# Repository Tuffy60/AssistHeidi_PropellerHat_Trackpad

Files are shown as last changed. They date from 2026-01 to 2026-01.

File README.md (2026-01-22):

# ASSIST HEIDI – Assistive Input System

ASSIST HEIDI is an assistive input system developed to provide alternative and accessible input devices for users who experience difficulties using standard mouse and keyboard setups.  
The project focuses on reducing physical strain while maintaining precise and responsive control, especially for fast-paced applications such as shooter games.

This repository contains the complete firmware, hardware design files, and documentation created as part of the ASSIST HEIDI project.

---

## Project Background

The project was developed in close collaboration with a user who experiences rapid fatigue and reduced precision when using conventional input devices.  
Standard gaming peripherals often require continuous hand positioning, repetitive movements, and frequent button presses, which can significantly limit comfort and usability over longer sessions.

ASSIST HEIDI aims to address these challenges by offering customizable and modular input solutions that adapt to individual needs rather than forcing the user to adapt to the device.

---

## Features

- Assistive **trackpad-based controller** for precise cursor movement
- **Two easily accessible buttons** for mouse or keyboard actions
- **Seven-switch mini keyboard controller** with fully customizable mappings
- Adjustable firmware parameters:
  - cursor speed
  - sensitivity
  - rotation (0°, 90°, 180°, 270°)
- Standard **USB Human Interface Device (HID)** behavior
- Plug & Play – no additional drivers required
- Platform independent (Windows, macOS, Linux)

---

## Repository Structure

- [firmware/trackpad_input](firmware/trackpad_input/) – Assistive trackpad and button input module
- [firmware/Keyboard_Switch](firmware/Keyboard_Switch/) – Assistive Keyboard for game controls  
- [hardware/3D_prints](hardware/3D_print/) – 3D printable parts

---
## Firmware

The firmware is implemented using the **Arduino framework** and runs on the **Raspberry Pi Pico W**.  
All configuration parameters are defined directly in the source code:

- `.h` files contain configurable mappings and feature definitions  
- `.cpp` files control behavior such as sensitivity, speed, and smoothing  

The device is recognized by the host system as a standard mouse and keyboard using USB HID.

---

## Hardware

The controllers are built using off-the-shelf components and 3D-printed enclosures.  
No specialized manufacturing tools are required, making the system easy to reproduce and modify.

3D printing files are provided in the [hardware/3D_prints](hardware/3D_print/) directory.

---

## Documentation

A detailed project documentation including:
- problem description
- solution overview
- materials and costs
- technical details
- assembly instructions

is available as a PDF in this repository:

📄 [PropellerHat-Controller_Documentation.pdf](PropellerHat-Controller_Documentation.pdf)

---

## License

This project is released under the **MIT License**.  
You are free to use, modify, and distribute the code and design files.

---

## Contributors

- Ates Tufan  
- Jakob Brandstetter  
- Matteo Fachino

---

## Acknowledgements

This project was developed as part of the **ASSIST HEIDI** initiative and builds upon previous assistive controller concepts.  
Special thanks to the user involved in the co-creation process for valuable feedback and continuous testing.

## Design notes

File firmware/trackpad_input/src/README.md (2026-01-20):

# Assistive Trackpad & Button Input Module (Arduino / USB HID)

This repository contains the implementation of an **assistive input system**
developed as part of the **ASSIST HEIDI** project.
The system is designed for people with **motor impairments affecting hands,
arms or overall body coordination** and provides an alternative way to
interact with a computer using minimal and controlled movements.

The device behaves as a standard USB mouse and keyboard and does not require
any special drivers on the host system.

---

## Overview

The system consists of the following components:

- A Cirque capacitive trackpad used as a pointing device  
- Two hardware buttons configurable as mouse or keyboard inputs  
- A USB HID interface exposing mouse and keyboard functionality  

The implementation focuses on:

- Accessible and low-fatigue interaction  
- Stable and predictable cursor movement  
- Suppression of involuntary micro movements  
- Deterministic behavior without automatic guessing  
- Clear separation of software modules  

---

## Features

- USB HID mouse and keyboard support  
- Configurable hardware buttons  
- Trackpad movement with deadzone, acceleration and smoothing  
- Controlled edge scrolling  
- Explicit rotation modes (0°, 90°, 180°, 270°)  
- Non-blocking input handling  
- Fully documented and modular code structure  

---

## Project Structure
.
├── main.cpp # Application entry point
├── trackpad.h # Trackpad interface and data structures
├── trackpad.cpp # Trackpad processing logic
├── buttons.h # Button configuration and action definitions
├── buttons.cpp # Button handling and HID actions
├── cirque.h # Cirque trackpad driver (external)
├── cirque.cpp # Cirque trackpad driver (external)
└── README.md

---

## Hardware Requirements

- Arduino-compatible microcontroller with native USB support  
  (e.g. RP2040, ATmega32U4, etc.)
- Cirque capacitive trackpad
- Two momentary push buttons
- USB connection to host PC

---

## Software Requirements

- Arduino framework
- USB HID support (`Mouse.h`, `Keyboard.h`)
- Compatible board package for the target microcontroller

---

### Supported Mouse Actions

The hardware buttons can be mapped to:

- Left mouse click  
- Right mouse click  
- Middle mouse click  
- Back and forward navigation buttons  

These actions enable basic system interaction without requiring precise or
fast finger movements.

### Supported Keyboard Actions

Buttons can also be mapped to keyboard inputs, including:

- Alphanumeric keys (e.g. W, A, S, D)  
- Arrow keys (Up, Down, Left, Right)  
- Modifier keys (Shift, Ctrl, Alt)  
- Common control keys (Space, Enter, Escape, Tab)  
- Function keys (F1 – F12)  

Each button generates a **press event when activated** and a **release event
when released**, ensuring stable and predictable USB HID behavior.

---

## Configuration Overview

### Button Configuration

Button behavior is configured in `buttons.h` using preprocessor definitions:

cpp
#define BUTTON1_ACTION   ACT_MOUSE_LEFT
#define BUTTON2_ACTION   ACT_MOUSE_RIGHT

Changing these values assigns a different mouse or keyboard action to the
corresponding hardware button.

This allows caregivers or developers to adapt the device to individual user
needs without modifying the button logic itself.

## Trackpad Movement and Accessibility Tuning

The trackpad behavior can be adjusted via `#define` parameters in
`trackpad.cpp` to match individual motor abilities.

Key parameters include:

- `SENS` – overall cursor movement speed  
- `SMOOTHING` – balance between responsiveness and stability  
- `DEADZONE_CENTER` – suppression of involuntary micro movements  
- `EDGE_SPEED_BASE` / `EDGE_SPEED_MAX` – controlled edge scrolling  

All parameters are documented directly in the source code.

---

## Assistive Design Principles

- Focus on stability rather than raw speed  
- Deterministic input behavior without automatic guessing  
- Minimal required movement for common actions  
- Adaptable configuration for different physical limitations  
- Designed for long-term and everyday use  

This module represents the technical implementation of the assistive input
concept developed within the **ASSIST HEIDI** project.

---

## Usage

1. Flash the firmware to the target microcontroller  
2. Connect the device to a PC via USB  
3. The device appears as a standard mouse and keyboard  
4. Use the trackpad for cursor movement  
5. Use the hardware buttons for mouse or keyboard actions  

No additional drivers are required.

---

This module was implemented and documented as part of an academic project.

Propeller-Controller

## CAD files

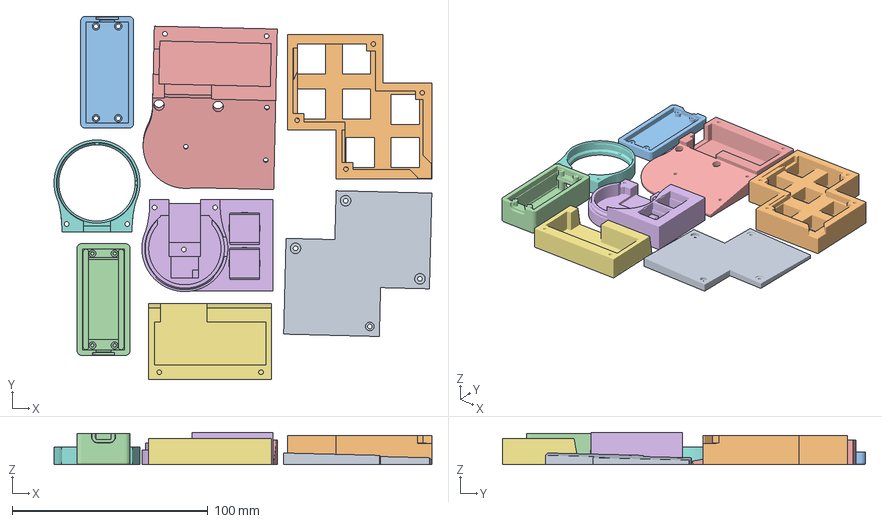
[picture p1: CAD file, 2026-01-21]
hardware/3D_print/Total_Project_Printing.3mf
193.4 x 185.8 x 16.5 mm
Base_slope5_7Switches_.stl
Main_7Switches_.stl
Botttom_case.stl
Top_case.stl
Base_TouchPad.stl
Main_TouchPad.stl
MicroController_Lid_TouchPad.stl
Top_TouchPad.stl

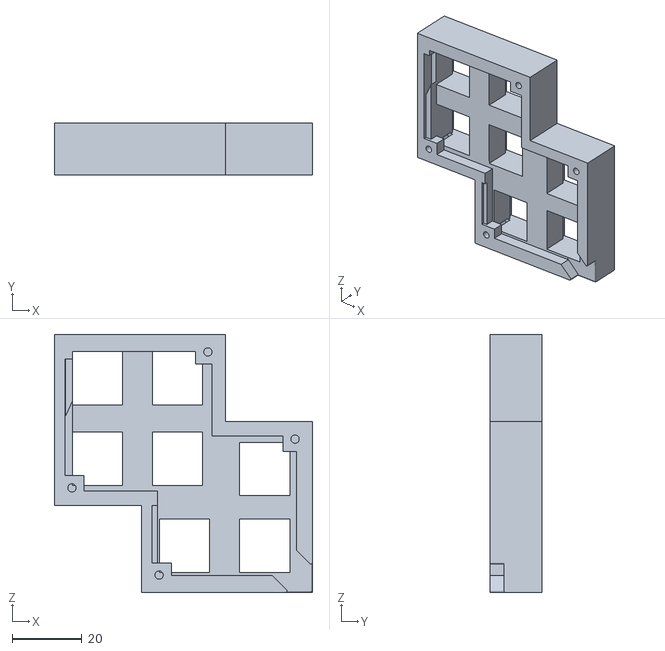
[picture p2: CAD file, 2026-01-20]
hardware/3D_print/7Switches/Main_7Switches_.stl
74.0 x 15.0 x 74.0

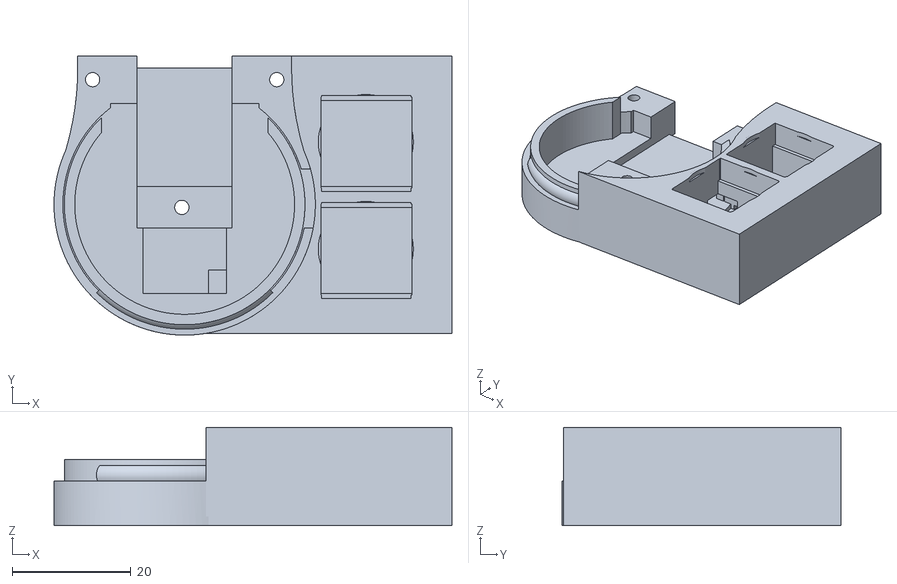
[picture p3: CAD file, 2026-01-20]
hardware/3D_print/TouchPad/Main_TouchPad.stl
67.0 x 47.0 x 16.5

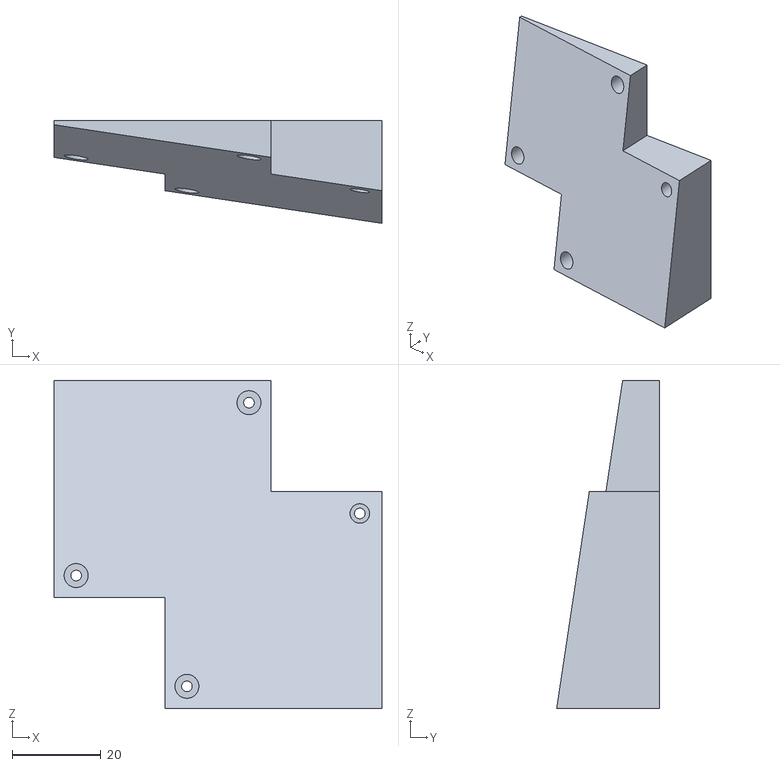
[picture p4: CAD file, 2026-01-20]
hardware/3D_print/7Switches/Base_slope23_7Switches_.stl
74.0 x 23.2 x 74.0

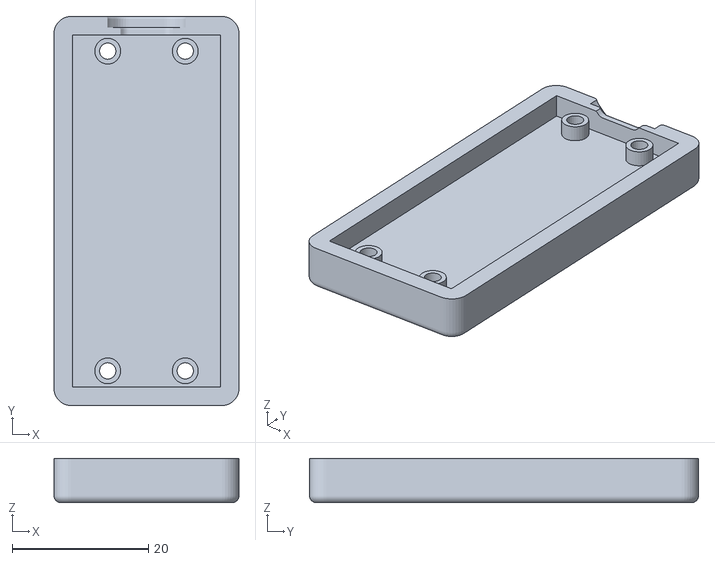
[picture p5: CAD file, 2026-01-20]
hardware/3D_print/Microcontroller_Case/Botttom_case.stl
27.2 x 57.2 x 6.50

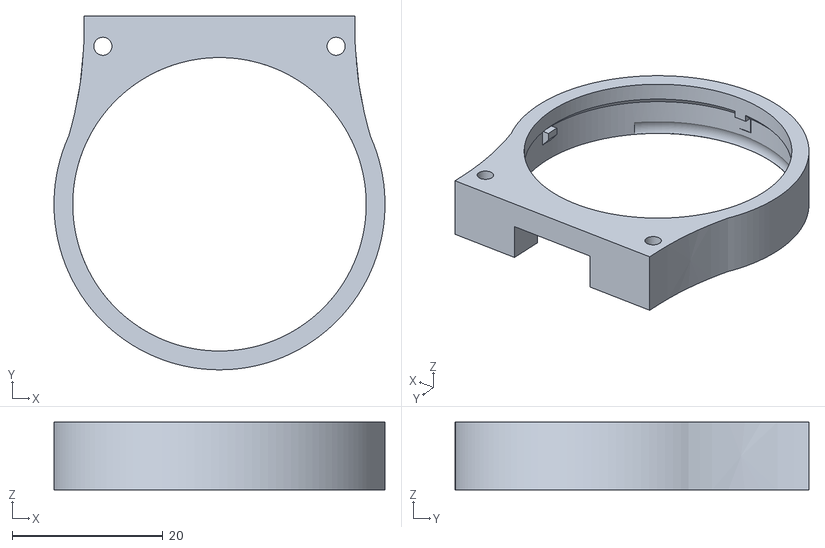
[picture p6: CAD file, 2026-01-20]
hardware/3D_print/TouchPad/Top_TouchPad.stl
44.0 x 47.0 x 9.00

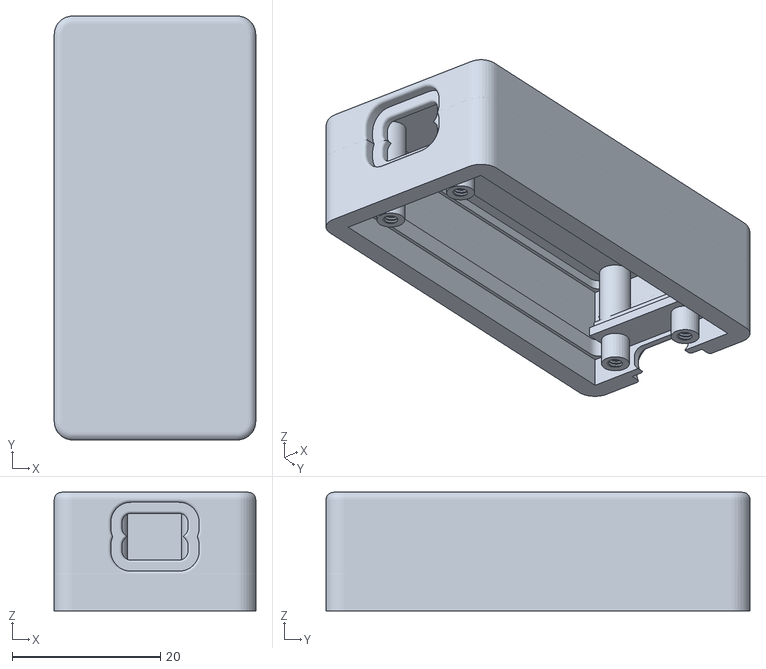
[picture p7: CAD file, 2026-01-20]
hardware/3D_print/Microcontroller_Case/Top_case.stl
27.2 x 57.2 x 16.0

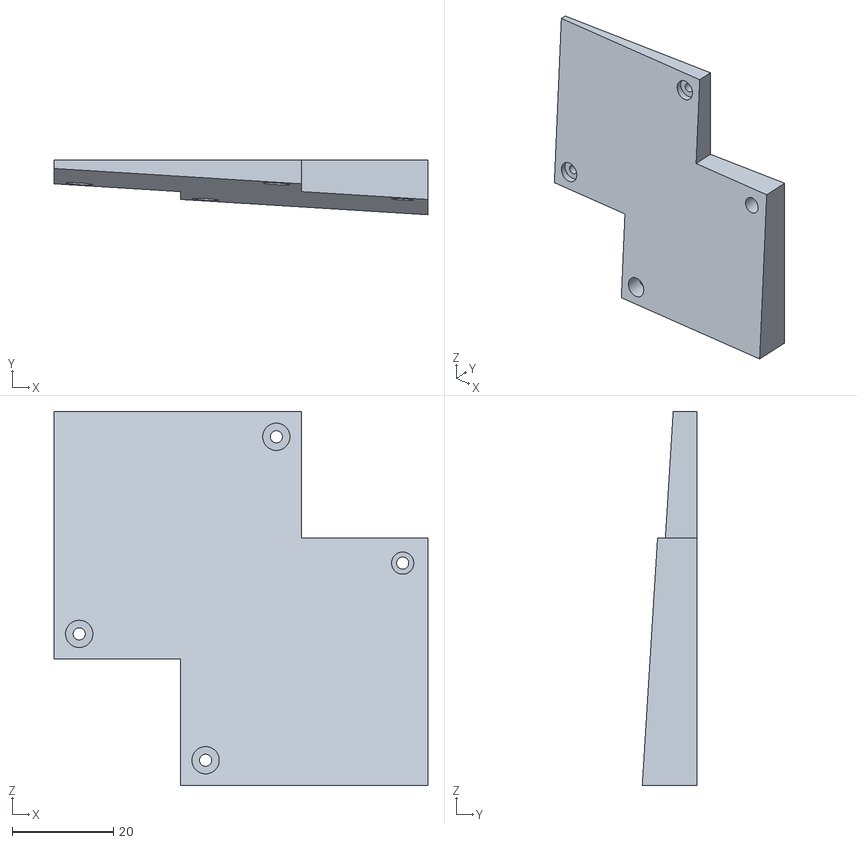
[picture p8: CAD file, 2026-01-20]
hardware/3D_print/7Switches/Base_slope10_7Switches_.stl
74.0 x 10.8 x 74.0

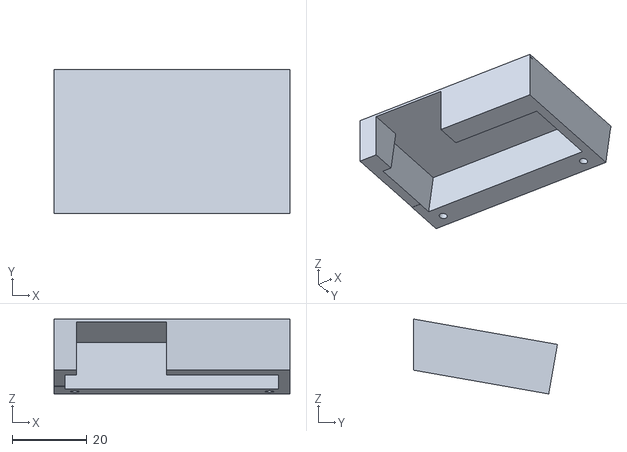
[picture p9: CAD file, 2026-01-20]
hardware/3D_print/TouchPad/MicroController_Lid_TouchPad.stl
63.0 x 38.4 x 20.0

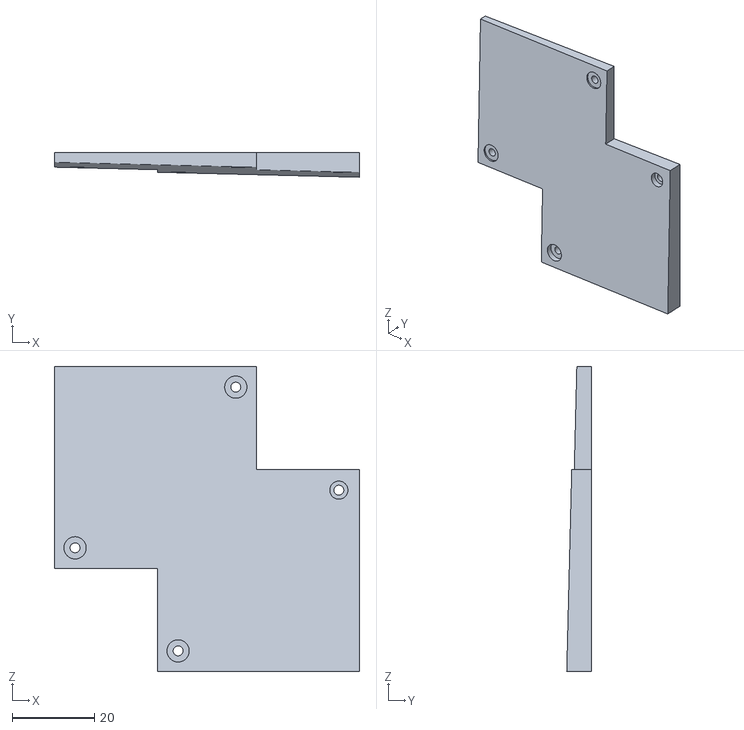
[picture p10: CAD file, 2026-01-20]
hardware/3D_print/7Switches/Base_slope5_7Switches_.stl
74.0 x 5.95 x 74.0

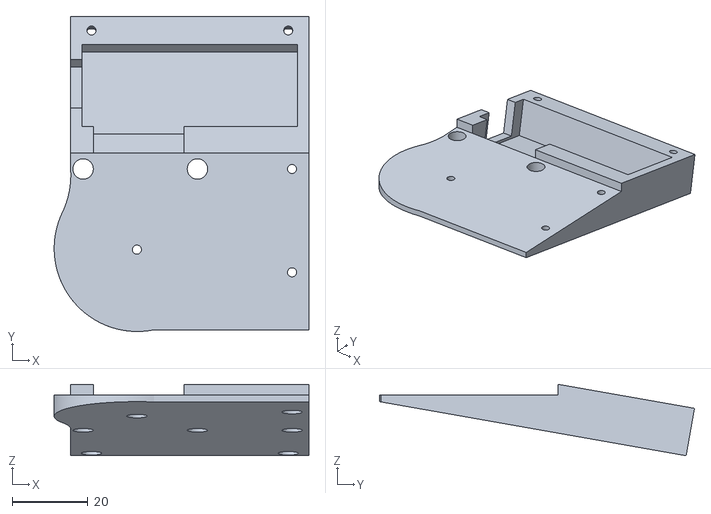
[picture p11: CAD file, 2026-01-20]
hardware/3D_print/TouchPad/Base_TouchPad.stl
67.3 x 83.2 x 18.9

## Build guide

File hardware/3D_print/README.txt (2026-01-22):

In this directory you find the 3 elemente of our design:
1) TouchPad Controller
2) 7 Switches - kebors controller
3) Secondary microcontroller case

and also the printing project with all components 'Total_Project_Printing.3mf'

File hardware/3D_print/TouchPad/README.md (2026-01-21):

In this folder you can find the design of Touchpad Controller, 
that consists of four distinct printed components:
1)	Inclined Base and Lower Housing (Base_TouchPad.stl)
This part provides the ergonomic tilt and forms the lower shell of the enclosure.
2)	Microcontroller Compartment Lid (MicroController_Lid_TouchPad.stl)
 A removable cover that protects the microcontroller and allows access for wiring and   maintenance.
3)	Main Body with Touchpad Mount and Switch Compartments (Main_TouchPad.stl)  
This central block integrates the mounting surface for the touchpad and the housing for the two auxiliary switches.
4)	Touchpad Outer Frame  (Top_TouchPad.stl)
A protective enclosure that secures the touchpad in place while leaving the active surface fully accessible.

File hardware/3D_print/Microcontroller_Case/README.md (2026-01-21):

In this folder you can find the design of Secondary Microcontroller Case:
1)	Base Plate (Bottom_case.stl)
2)	Top Cover (Top_case.stl)

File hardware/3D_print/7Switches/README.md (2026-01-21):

In this folder you find the /switches design that consist of two parts:

1)	Switch Mounting Base (Main_7Switches_.stl)
Designed to hold seven mechanical switches in a fixed and stable configuration.

3)	Inclined Lower Base (Base_slope5_7Switches_.stl,Base_slope10_7Switches_.stl,Base_slope23_7Switches_.stl) 
Available in two different tilt angles (height 5, 10 and 23), allowing users to select the most comfortable ergonomic orientation

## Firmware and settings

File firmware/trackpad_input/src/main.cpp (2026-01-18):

#include <Arduino.h>
#include <Mouse.h>
#include <Keyboard.h>
#include "Buttons.h"
#include "Trackpad.h"

/// @brief Arduino setup function
/// @details This function initializes all required hardware modules.
///          It starts the USB HID interfaces (mouse and keyboard),
///          initializes the button handling logic and the trackpad.
void setup() {
    Mouse.begin();
    Keyboard.begin();
    initButtons();
    initTrackpad();
}

/// @brief Arduino main loop
/// @details This function is executed continuously.
///          It updates the button states, reads and processes trackpad
///          input and sends mouse movement events via USB HID.
///          The loop runs without blocking delays to ensure responsive
///          input handling.
void loop() {

    // Update button states and trigger mouse/keyboard actions
    updateButtons();

    // Read processed trackpad movement
    TrackpadProcessed p = updateTrackpad();

    // Send mouse movement only if a finger is detected
    if (p.fingerPresent) {

        // Limit movement values to valid HID range
        int8_t mx = constrain((int)p.dx, -127, 127);
        int8_t my = constrain((int)p.dy, -127, 127);

        // Send relative mouse movement
        Mouse.move(mx, my);
    }

    // Small delay to stabilize USB HID communication
    delay(1);
}

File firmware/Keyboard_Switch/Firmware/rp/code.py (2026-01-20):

import board
import digitalio
import time
import usb_hid
from adafruit_hid.keyboard import Keyboard
from adafruit_hid.keycode import Keycode

# --- Setup USB HID Keyboard ---
keyboard = Keyboard(usb_hid.devices)

# --- CONFIGURATION ---

# Keycode list for easy assignment of 0-9
NUMBERS_0_TO_9_KEYCODES = [
    Keycode.ZERO, Keycode.ONE, Keycode.TWO, Keycode.THREE, Keycode.FOUR,
    Keycode.FIVE, Keycode.SIX, Keycode.SEVEN, Keycode.EIGHT, Keycode.NINE
]

# Fixed pin ordering (IMPORTANT!)
PIN_ORDER = [
    board.GP0, board.GP1, board.GP2, board.GP3, board.GP4,
    board.GP5, board.GP6, board.GP7, board.GP8, board.GP9
]

# Single-key mapping
SINGLE_KEY_PINS = {
    board.GP0: NUMBERS_0_TO_9_KEYCODES[0],
    board.GP1: NUMBERS_0_TO_9_KEYCODES[1],
    board.GP2: NUMBERS_0_TO_9_KEYCODES[2],
    board.GP3: NUMBERS_0_TO_9_KEYCODES[3],
    board.GP4: NUMBERS_0_TO_9_KEYCODES[4],
    board.GP5: NUMBERS_0_TO_9_KEYCODES[5],
    board.GP6: NUMBERS_0_TO_9_KEYCODES[6],
    board.GP7: NUMBERS_0_TO_9_KEYCODES[7],
    board.GP8: NUMBERS_0_TO_9_KEYCODES[8],
    board.GP9: NUMBERS_0_TO_9_KEYCODES[9]
}

# Two-button combinations
COMBINATION_PINS_NUMERIC = {
    (0, 1): Keycode.A, (0, 2): Keycode.B, (0, 3): Keycode.C, (0, 4): Keycode.D,
    (0, 5): Keycode.E, (0, 6): Keycode.F, (0, 7): Keycode.G, (0, 8): Keycode.H,
    (0, 9): Keycode.I, (1, 2): Keycode.J,

    (1, 3): Keycode.K, (1, 4): Keycode.L, (1, 5): Keycode.M, (1, 6): Keycode.N,
    (1, 7): Keycode.O, (1, 8): Keycode.P, (1, 9): Keycode.Q, (2, 4): Keycode.R,
    (2, 5): Keycode.S, (2, 6): Keycode.T, (2, 7): Keycode.U, (2, 8): Keycode.V,
    (2, 9): Keycode.W, (3, 4): Keycode.X, (3, 5): Keycode.Y, (3, 6): Keycode.Z,

    (3, 7): Keycode.SPACE,
    (3, 8): Keycode.ENTER,
    (3, 9): Keycode.ESCAPE,
    (4, 5): Keycode.DELETE,
    (4, 6): Keycode.TAB,
    (4, 7): Keycode.LEFT_SHIFT,
    (4, 8): Keycode.LEFT_CONTROL,
    (4, 9): Keycode.LEFT_ALT,
    (5, 6): Keycode.F1,
    (5, 7): Keycode.F12,
}

# --- Initialization ---

pin_to_number_map = {}
button_pins = []
SINGLE_PIN_KEYCODES_LOOKUP = {}

# Guarantee correct numbering 0–9
for i, board_pin_object in enumerate(PIN_ORDER):
    button = digitalio.DigitalInOut(board_pin_object)
    button.direction = digitalio.Direction.INPUT
    button.pull = digitalio.Pull.UP
    button_pins.append(button)

    pin_to_number_map[button] = i
    SINGLE_PIN_KEYCODES_LOOKUP[button] = SINGLE_KEY_PINS[board_pin_object]

# Current pressed state
currently_pressed_keys = []

print("Keyboard script running with correct combination detection.")

# --- Stabilization Debounce ---

def stabilize_input(buttons):
    """Waits 50ms to allow multi-button presses to settle."""
    is_pressed = any(not b.value for b in buttons)
    if is_pressed:
        time.sleep(0.05)
    return is_pressed

# --- Determine desired keycode ---

def get_desired_keycode(current_pressed_pin_numbers):

    pressed_combo_tuple = tuple(sorted(list(current_pressed_pin_numbers)))

    # Try combos (2 or more buttons)
    if len(pressed_combo_tuple) >= 2:
        if pressed_combo_tuple in COMBINATION_PINS_NUMERIC:
            return COMBINATION_PINS_NUMERIC[pressed_combo_tuple]

    # Single button
    if len(pressed_combo_tuple) == 1:
        pin_index = pressed_combo_tuple[0]
        pin_object = button_pins[pin_index]
        return SINGLE_PIN_KEYCODES_LOOKUP[pin_object]

    return None


# --- Main Loop ---

while True:

    if not stabilize_input(button_pins):
        if currently_pressed_keys:
            keyboard.release_all()
            currently_pressed_keys = []
            print("All Released")
        time.sleep(0.01)
        continue

    # Gather pressed inputs
    current_pressed_pin_numbers = set()
    for pin in button_pins:
        if not pin.value:
            current_pressed_pin_numbers.add(pin_to_number_map[pin])

    # Look up output key
    desired_keycode = get_desired_keycode(current_pressed_pin_numbers)

    # Send HID output
    if desired_keycode is not None:
        if currently_pressed_keys != [desired_keycode]:
            keyboard.release_all()
            keyboard.press(desired_keycode)
            currently_pressed_keys = [desired_keycode]
            print("Key Sent:", desired_keycode)

    time.sleep(0.01)

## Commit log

2026-01-18 Initial commit: Assistive trackpad and button input module (ASSIST HEIDI)
2026-01-20 Initial commit: ASSIST HEIDI PropellerHat Trackpad Controller
    This commit includes:
    - Assistive trackpad controller firmware
    - Modular repository structure
    - Project documentation and README
    - Repository cleanup and licensing
2026-01-20 Add README for 7 Switches
2026-01-20 Add README for microcontroller case
    Added a README file with a description of the microcontroller case.
2026-01-20 added missing files
    added missing files
    [code.py]
2026-01-21 Create README for 3D print hardware components
    Added a README file describing the 3D print hardware components.
2026-01-21 Enhance README with 7 Switches design details
    Added detailed description of the 7 Switches design components and their purpose.
2026-01-21 Add design details for Secondary Microcontroller Case
    Updated README to include details about microcontroller case designs.
2026-01-21 Update README to include printing project details
    Added a note about the printing project and components.
2026-01-21 Update README with total project printing file reference
2026-01-22 Fix link to 3D printable parts directory
2026-01-22 Fix capitalization in 3D prints directory name
2026-01-22 Update link to 3D printing files directory
